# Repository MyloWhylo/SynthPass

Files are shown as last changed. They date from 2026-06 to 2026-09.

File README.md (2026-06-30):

# SynthPass

An open-source protocol & hardware design for to detect nose boops & transfer simple data, designed for protogen/synth fursuits.

Built to solve a very important problem. With SynthPass, you won't have to break character or pull off your paws and fumble with your phone to trade contact details. Just nose-boop, and SynthPass will automagically trade a small chunk of user-defined data, like a web link, username, or anything else that can fit in a couple hundred bytes of plain text. Then plug in your SynthPass at the end of the day and download all the data you've collected.

SynthPass is also designed to easily interface with nearly any protogen/synth fursuit. SynthPass hardware can be powered by a single 3.3V supply, and supports digital several digital interface options.

## Features

- ### Simple interface to fursuits
	- GPIO: pin HIGH (3.3V) when booped, LOW (0V) when not booped. Additional pin that's high
	- UART: Message for boop start/end
	- I2C: Register for boop status
    - Don't want to modify your firmware or connect the digital pins to your controller? The GPIO output can also drive an LED to indicate when another SynthPass is nearby and when a nose boop is detected.
- ### Advanced interface
	- UART/I2C Only
	- Approximate range & unique ID of peer prior to boop
	- Extra boop parameters (e.g. boop expression, color, name/species of peer)
- ### USB interface
    - Mass storage device for downloading collected data. Simply plug in the SynthPass into a computer and open `MESSAGES.HTM` in your web browser.
        - Edit the files `ME/BOOP.TXT` and `ME/PROX.TXT` to set your own messages to be transferred on proximity/boop
        - Edit `ME/SYNTHPAS.INI` to change settings for LED behavior, boop range, and enable proximity messages
    - Software bootloader switch for firmware updates over USB - send the character 'b' to the USB TTY that appears to switch to the USB bootloader.
## Hardware
SynthPass is based on the ultra-low-cost WCH CH57x series microcontrollers.
- ## 2.4GHz radio
	- Boop detection by RSSI (radio signal strength)
	- ISLER protocol for peer-to-peer and broadcast communication without need for pairing
	- CH572 also supports BLE (possibility for future companion app?)
- ## Protogen/Synth Suit Interface
	- 4-pin JST SH connector, compatible with QWIIC/Stemma QT (TODO?)
	- Single 3.3V input (possibly support 5V input with some hardware designs)
	- Option for I2C, UART, or GPIO communication protocol
	- Designed for easy integration with most synth/protogen heads

## Software
Using CH32Fun + iSLER library for communication

SynthPass communicates using BLE advertising frames with a fixed MAC address so that SynthPassdevices can easily be detected.

Communication (currently) uses a fixed channel (Channel 37) and PHY mode (1Mbps).

TODO document stuff better :3

## Development

**Building SynthPass**

SynthPass uses PlatformIO to manage the firmware toolchain, and the ch32fun framework to handle the ch572's hardware interfaces.

To compile the firmware, you'll need to:

- Clone the SynthPass repo `git clone https://github.com/JackToaster/SynthPass.git`
- Clone the ch33fun repo `git clone https://github.com/cnlohr/ch32fun.git`
- Run `pio run -e [board hardware target]`. `[board hardware target]` should be replaced with one of the targets defined in `platformio.ini`:
  - `nanoch57x` for the nanoch57x dev board
  - `pretzelslab` for the SynthPass hardware in this repo & the SynthPasses handed out at Anthrocon 2026
  - `axionqc` for AxionQc's hardware design

**Updating firmware**

We have a custom upload script built into the PlatformIO configuration for SynthPass, all you need to do to update the firmware is:

`pio run -e [board target] -t upload`

for the "official" Pretzel's Lab hardware: `pio run -e pretzelslab -t upload`

If the firmware is borked and the flashing script doesn't work, hold down the boot button while plugging in the SynthPass to force it into ISP bootloader mode.

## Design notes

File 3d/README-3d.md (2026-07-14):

# SynthPass 3d models

Source files for enclosure/Onshape model of SynthPass R1 PCB [here](https://cad.onshape.com/documents/bf931ddadb22dfcf7c4a1b5d/w/87cdca24849746962069b11e/e/08bf58ecdb490120764283a6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)

STEP/STL files of the enclosure are also included in this folder.

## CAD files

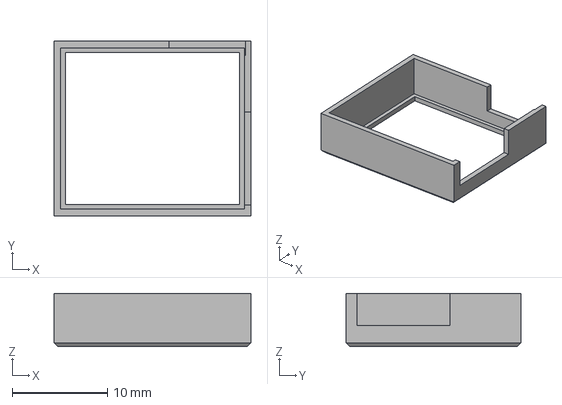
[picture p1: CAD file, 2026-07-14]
3d/synthpass-r1-shell-btm.step
20.7 x 18.3 x 5.60 mm

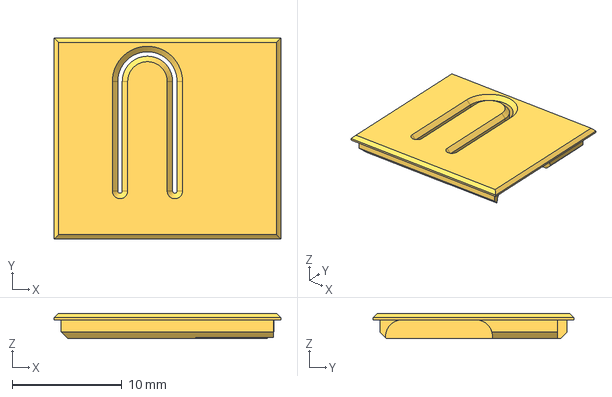
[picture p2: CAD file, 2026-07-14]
3d/synthpass-r1-shell-top.step
20.7 x 18.3 x 2.32 mm

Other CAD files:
3d/synthpass-r1-shell-btm.stl
3d/synthpass-r1-shell-top.stl

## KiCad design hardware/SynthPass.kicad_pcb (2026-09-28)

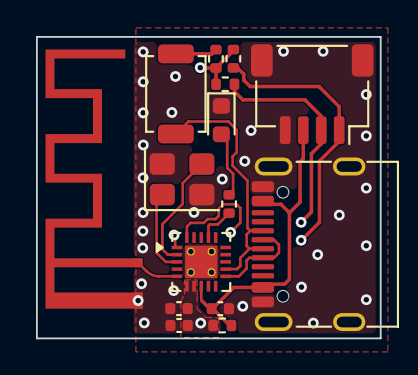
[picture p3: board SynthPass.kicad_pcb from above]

Board: 4 copper layers, 19.1 x 16.8 mm, 15 parts (0 on the bottom side), 13 nets.

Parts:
AE1: SWRA117D; Texas_SWRA117D_2.4GHz_Right
C1, C3: 10u; C_0402_1005Metric
C4: 0.1u; C_0402_1005Metric
D1: LED_Small; LED_0603_1608Metric
J1: SM04B-SRSS-TB; JST_SH_SM04B-SRSS-TB_1x04-1MP_P1.00mm_Horizontal
J2: USB_C_Receptacle_USB2.0_16P; USB_C_Receptacle_G-Switch_GT-USB-7010ASV
R1, R5: 1K5; R_0402_1005Metric
R2, R3, R4: 5.1k; R_0402_1005Metric
SW1: SW_Push; SW_SPST_TS-1088-xR020
U1: CH572D; CH572D_New
Y1: 32MHz; Crystal_SMD_3225-4Pin_3.2x2.5mm

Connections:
+3V3: C3.1, C4.1, R1.2, R3.2, R4.2, R5.2, U1.6 (VDD33), U1.7 (VIO33)
/ANT: AE1.1 (FEED), U1.5 (ANT)
/XI: U1.3 (XI), Y1.1
/XO: U1.2 (XO), Y1.3
GND: AE1.2 (PCB_Trace), C1.2, C3.2, C4.2, D1.1 (K), J1.4, J1.MP (MountPin), J2.A1 (GND), J2.A12 (GND), J2.B1 (GND), J2.B12 (GND), J2.SH (SHIELD), U1.0 (GND), Y1.2, Y1.4
unnamed: D1.2 (A), R2.2
unnamed: R1.1, SW1.2
unnamed: R2.1, U1.17 (PA10)
SCL: J1.1, R3.1, U1.1 (SCL)
SDA: J1.2, R4.1, U1.20 (SDA)
UDN: J2.A7 (D-), J2.B7 (D-), U1.11 (UDM)
UDP: J2.A6 (D+), J2.B6 (D+), SW1.1, U1.12 (UDP)
VBUS: C1.1, J1.3, J2.A4 (VBUS), J2.A9 (VBUS), J2.B4 (VBUS), J2.B9 (VBUS), R5.1, U1.8 (V5)

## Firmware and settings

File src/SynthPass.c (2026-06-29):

/*
 * SynthPass -- firmware entry point.
 *
 * A protogen/synth nose-boop gadget on the WCH CH572. Subsystems:
 *   - radio.c    : 2.4GHz iSLER radio + SynthPass protocol (peer detect, PROX)
 *   - usb.c      : composite USB -- CDC debug serial + read-only MSC mass storage
 *   - msgstore.c : flash-backed message store (read by the MSC layer)
 *
 * This file wires them together and runs the main loop.
 */
#include "ch32fun.h"
#include "ch5xxhw.h"   // jump_isprom
#include <stdio.h>     // putchar (defined in usb.c)

#include "usb.h"
#include "msgstore.h"
#include "radio.h"
#include "config.h"
#include "synthpass.h"
#include "board.h"

SynthPass_PeerState_T peers[MAX_PEERS];

void blink(int n) {
	for(int i = n-1; i >= 0; i--) {
		LED_ON();
		Delay_Ms(33);
		LED_OFF();
		if(i) Delay_Ms(33);
	}
}

int main()
{
	SystemInit();

	funGpioInitAll();
	funPinMode( LED_PIN, GPIO_CFGLR_OUT_10Mhz_PP );
#ifdef HAVE_QWIIC_GPIO
	funPinMode( QWIIC_PROX_PIN, GPIO_CFGLR_OUT_10Mhz_PP );
	funPinMode( QWIIC_BOOP_PIN, GPIO_CFGLR_OUT_10Mhz_PP );
	funDigitalWrite( QWIIC_PROX_PIN, FUN_LOW );
	funDigitalWrite( QWIIC_BOOP_PIN, FUN_LOW );
#endif

	msgstore_init(); // seed the message store into flash if needed
	config_init();   // load host-editable config (or defaults) from its sector
	usb_init();      // bring up CDC + MSC
	radio_init();    // protocol state + iSLER radio; start broadcasting

	blink(1);

	while(1) {
		// CDC debug input: 'b' jumps to ROM bootloader, anything else is echoed.
		int c = usb_cdc_getc();
		if(c >= 0) {
			if(c == 'b') {
				blink(5);
				usb_reset();
				jump_isprom(); // enters the USB ISP bootloader; does not return
			} else {
				putchar(c);
			}
		}

		usb_task();    		// handle MSC transfer. returns immediately if no usb transfer happening.
		radio_task(peers);  // radio rx + periodic broadcast
	}
}

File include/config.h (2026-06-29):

#ifndef SYNTHPASS_CONFIG_H
#define SYNTHPASS_CONFIG_H

#include <stdint.h>

// Host-editable parameters, persisted in a dedicated 4 KB sector inside the
// message store (see msgstore.c CONFIG_OFF). Read into the cached struct at
// boot; rewritten when the host edits ME/synthpass.ini and unmounts.
//
// Enum members are kept as uint8_t (rather than typed enums) so the cross-
// boundary struct stays 4 bytes and survives flash round-trip cleanly.

// led_behavior values:
#define LED_BEHAVIOR_BOOP   0  // on while any peer is booped (default)
#define LED_BEHAVIOR_PROX   1  // on while any peer is in proximity range
#define LED_BEHAVIOR_OFF    2  // always off

// data_trigger values:
#define DATA_TRIGGER_PROX_AND_BOOP 0  // send PROX_DATA and BOOP_DATA (default)
#define DATA_TRIGGER_BOOP_ONLY     1  // only send data on boop

// protocol_mode values:
#define PROTOCOL_GPIO     0  // PA2/PA3 as discrete GPIO (default)
#define PROTOCOL_I2C      1  // (future)
#define PROTOCOL_SERIAL   2  // (future)

typedef struct {
	int8_t  boop_rssi_adjust;  // dB offset added to BOOP_RSSI threshold (negative = easier boop)
	uint8_t led_behavior;
	uint8_t data_trigger;
	uint8_t protocol_mode;
} Config_T;

// Load cached config from flash; falls back to defaults if not initialized.
// Call once at boot, before USB or radio start.
void config_init(void);

// Pointer to the live config. Cheap, no I/O.
const Config_T *config_get(void);

// Replace the cached config by parsing `buf` (host wrote a new ME/synthpass.ini).
// Persists to flash and re-renders the synthesized .ini text. Unknown keys and
// malformed lines are silently dropped; unrecognized values fall back to the
// existing cached field.
void config_apply_text(const uint8_t *buf, uint16_t len);

// Synthesized .ini text for MSC reads of ME/synthpass.ini. Stable until the
// next config_init / config_apply_text. (Comments in host edits are NOT
// preserved -- the rendered text always reflects the current parsed values.)
const uint8_t *config_rendered(void);
uint16_t       config_rendered_len(void);

#endif

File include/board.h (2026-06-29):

#ifndef BOARD_H
#define BOARD_H

#include "ch32fun.h"

// Per-board pin map / behavior. The BOARD_* macro is set in each env's
// build_flags in platformio.ini.

// SYNTHPASS_REF_RSSI / SYNTHPASS_REF_RXRSSI are this board's RSSI calibration
// against the NanoCH57x reference: REF_RSSI is broadcast in each frame as our
// TX calibration ("how this board would appear at 1m on a reference receiver"),
// and REF_RXRSSI is subtracted from raw RSSI on receive to normalize against
// the reference RX sensitivity. NanoCH57x is the reference, so it -- and the
// generic dev board, which we treat as identical for now -- get 0/0.

#if defined(BOARD_GENERIC_CH572Q)
    // CH572Q dev board: active-low LED on PA11.
    #define LED_PIN   PA11
    #define LED_ON()  funDigitalWrite(LED_PIN, FUN_LOW)
    #define LED_OFF() funDigitalWrite(LED_PIN, FUN_HIGH)

    #define SYNTHPASS_REF_RSSI    0
    #define SYNTHPASS_REF_RXRSSI  0

#elif defined(BOARD_NANOCH57X)
    // NanoCH57x dev board (RSSI calibration reference).
    #define LED_PIN   PA11
    #define LED_ON()  funDigitalWrite(LED_PIN, FUN_LOW)
    #define LED_OFF() funDigitalWrite(LED_PIN, FUN_HIGH)

    #define SYNTHPASS_REF_RSSI    0
    #define SYNTHPASS_REF_RXRSSI  0

#elif defined(BOARD_PRETZELS_LAB_R1)
    // Official Pretzel's Lab SynthPass R1 board.
    // Active High LED on PA10
    #define LED_PIN   PA10
    #define LED_ON()  funDigitalWrite(LED_PIN, FUN_HIGH)
    #define LED_OFF() funDigitalWrite(LED_PIN, FUN_LOW)

    #define SYNTHPASS_REF_RSSI   -3
    #define SYNTHPASS_REF_RXRSSI -3

    // QWIIC port outputs: PA2 (SDA) high while any peer is in proximity range,
    // PA3 (SCL) high while any peer is booped. Push-pull, active high.
    #define HAVE_QWIIC_GPIO
    #define QWIIC_PROX_PIN PA2
    #define QWIIC_BOOP_PIN PA3

#elif defined(BOARD_AXION_QC_R1)
    // AxionQC's SynthPass hardware.
    #error "AxionQC hardware not implemented yet!"
#else
    #error "No BOARD_* macro defined; check platformio.ini env build_flags."
#endif

#endif // BOARD_H

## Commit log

2026-05-27 add preliminary (nfc) hardware
    [SynthPass.kicad_pcb, SynthPass.kicad_sch]
2026-05-28 File storage change - single MD stream for messages + separate storage for attachment files
2026-05-28 Message store cleanup and bugfixes
    [radio.c]
2026-05-28 Finalize hardware design, pending pinout confirmation
    [SynthPass-CuBottom.gbr, SynthPass-CuIn1.gbr, SynthPass-CuIn2.gbr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]
2026-06-19 Peer device state tracking and transmission queueing
2026-06-19 Add multiple board targets, LED/RSSI config
2026-06-29 Add config, fix USB MSC issues, boop transfers data
    [SynthPass.c, board.h, config.h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]
2026-07-11 Add 3d models
    [synthpass-r1-shell-btm.step, synthpass-r1-shell-btm.stl, synthpass-r1-shell-top.step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]
2026-09-28 Change CH572 symbol, change UDP resistor to 1K5, add 1K5 5V->3V3 resistor
    [SynthPass-CuBottom.gbr, SynthPass-CuIn1.gbr, SynthPass-CuIn2.gbr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]
2026-09-28 Add rev. # to schematic
    [SynthPass.kicad_sch]
2026-09-28 Add USB C 3d model, remove U1 silkscreen marking
    [SynthPass.kicad_pcb]
2026-09-28 Update back silk rev. # to track board revision
    [SynthPass.kicad_pcb]
